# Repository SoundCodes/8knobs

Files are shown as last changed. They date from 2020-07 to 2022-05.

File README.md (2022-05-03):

# 8knobs
### Introducing 8knobs
IMAGE ALT TEXT (https://www.youtube.com/watch?v=3tVFqUqmMqI "8knobs")

###### // Synth // Midi controller // educational module 

8knobs is a portable synthesizer and  midi controller. Right out of the box  8knobs creates drones and atmospheres (ambient soundscapes). 8knobs encourages learning  synthesis, electronics, computer literacy and experimentation. Built on the popular Arduino platform it readily embodies the character of the user. It is an open source and hacker friendly instrument, ready to morph according to a wide range of use cases.

8knobs can be used as a MIDI controller through usb, as a plug-n-play device; this means no installations, no additional convertors, no headaches. The 8knobs DIY  kit consists of a PCB, an Arduino Atmega 32u4, header pins, potentiometers, all the necessary electronic components, mounting hardware, a laser cut wood veneer body and a case made of hand stitched jute with raw unbleached cotton. 

8knobs has 1 audio out, MIDI over USB or MIDI over 3.5mm to connect to other traditional synthesisers. It can be powered via USB, DC 9-12v wall adaptor or a 9v battery.

#### DIY 

###### // Electronics // Sound synthesis // Computer Coding

While building 8knobs you’ll learn everything from the basics like soldering to the fundamentals of sound synthesis, electronics and computer codes by understanding, engineering and experimenting with signal flow. Learn the art of signal flow by building your own custom synthesiser and controller for more experiments!

####Experience 

###### // Creative learning and new approaches

Getting familiar with signal flow unlocks a wide range of new opportunities to innovate and produce technical as well as creative applications in various media - both analog and digital.

Just like the flow of signals in the brain are interconnected and influence each other. For example, like neurons communicating information in both chemical and electrical forms, can result in infinite combinations of  thoughts, words, and actions, similarly, playing with signal flow in hardware (electronics), software (coding) and space (acoustics) can result in infinite creative expressions.  

The art of signal flow offers endless possibilities, and whether you take it up as a hobby or use it to pursue a life-changing innovation is for you to choose. Either way, it’s a great feeling to get your hands dirty in the energetic flow of signals and DIY culture!

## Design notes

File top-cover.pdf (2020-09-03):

## step 1:

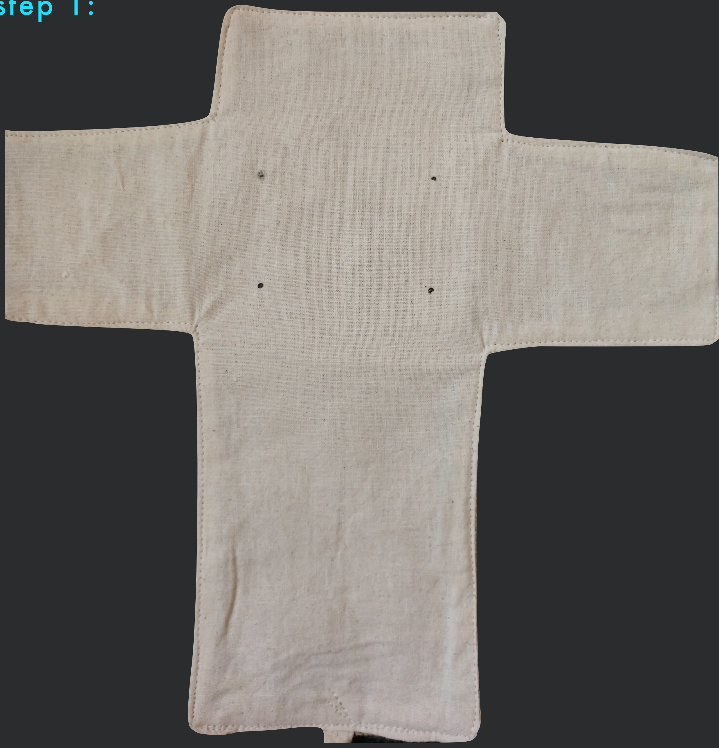
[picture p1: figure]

- Use the top cover to mark holes on the Jute cloth

## step 2:

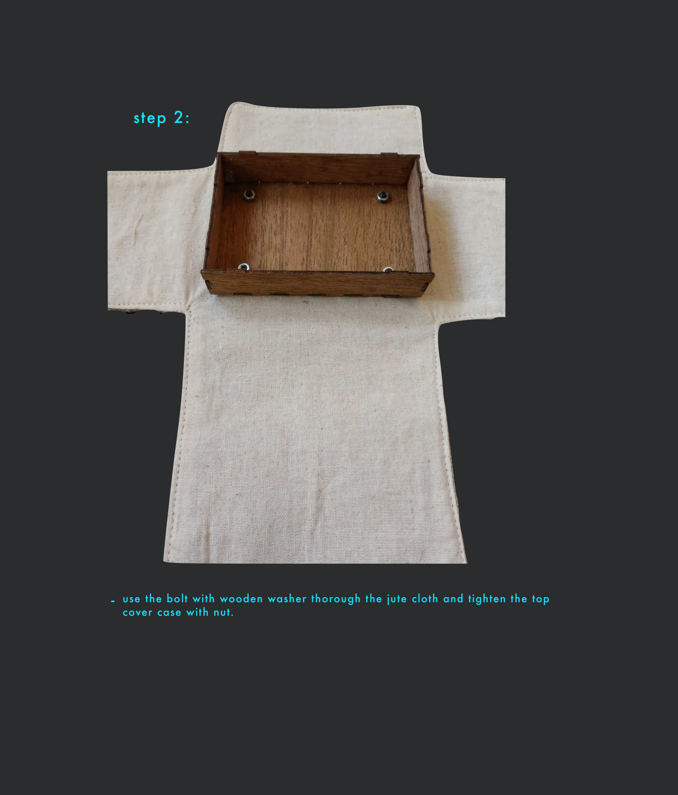
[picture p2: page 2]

- use the bolt with wooden washer thorough the jute cloth and tighten the top cover case with nut.

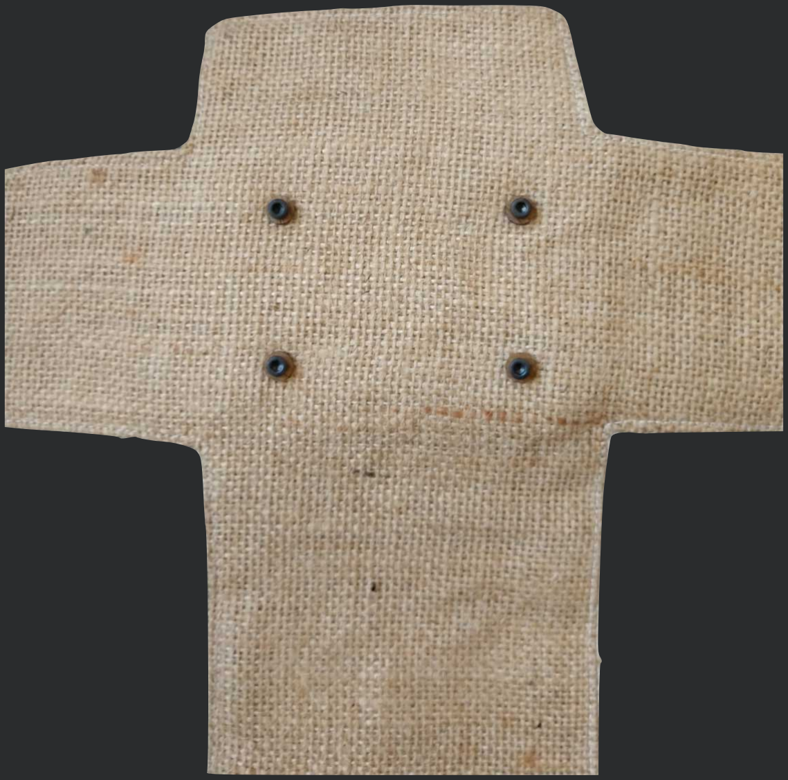
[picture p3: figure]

The Jute would look something like this after the process

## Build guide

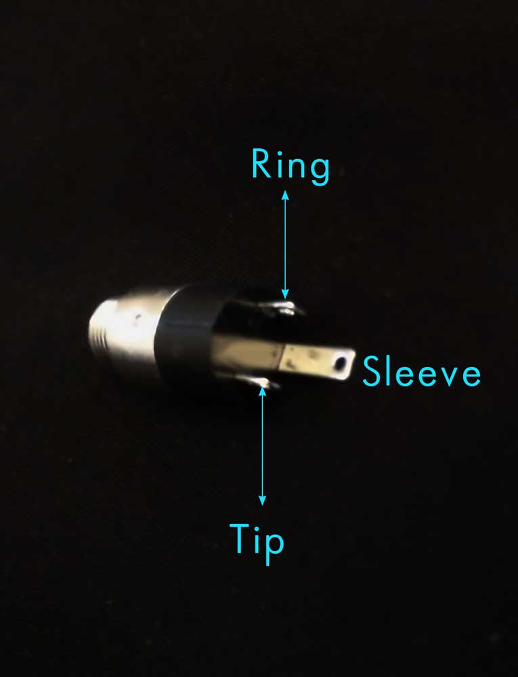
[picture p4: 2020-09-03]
DIY Instructions/3.5mm.jpg

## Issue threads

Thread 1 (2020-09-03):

Not clear how to solder jack for midi

60pfennig, 2020-09-03:
Hello :)
It is not clear for me which pin at the 3.5mm jack is for the tip and which is for the ring. Does it matter?
Greets Felix

SubstanceD, 2020-09-03:
Hey @60pfennig polarity of the 3.5mm stereo connector does matter.
On the back side of the connector it has tiny number printed. 1= tip, 2=ring
Also the below image may make it more clear.
https://github.com/SoundCodes/8knobs/blob/master/DIY%20Instructions/3.5mm.jpg

60pfennig, 2020-09-03:
Thanks for the clarification :)

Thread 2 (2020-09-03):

High Frequency Noise

60pfennig, 2020-09-03:
After soldering and assembling everything I tried 8knobs out. Everything works good but I get an very high pitched noise even if all oscillators are turned down. Is this because of the the arduino or did I made a mistake while soldering and there is flowing some current where it shouldnt flow?

SubstanceD, 2020-09-03:
Can be due to arduino or it can be one pot as well.. rapidly check which one is the culprit . This can be done by turning all pots down and rapidly turning one single pot to somewhere 30%-40% and bringing it back down to 0. Do this for all the pots.
If its on pot then its the soldering of the pot if not then its arduino. If its arduino then on the backside of the pcb you can solder an additional resistor anything between 10 to 100 ohm deadbug style.

If its pot then the easy fix is everytime do this action to the pot to cancel the Hi freq noise. ie bring it to some point like 30%-40% then rapidly bring it down.

60pfennig, 2020-09-03:
Ok, I cleaned all pcb because I thought maybe maybe the flux caused a current leak. Problem persists. I tried the knob thing. Every knob is modifying the volume of its osc. The hi freq still persists all the time on the same freq. On poti might be faulty, because even if I turn it completly down, the osc keeps playing on low rate.
To solver the hi freq problem I could try soldering an additional resistor. Where exactly should I solder it?

SubstanceD, 2020-09-03:
Ok..
R1 would be the place

60pfennig, 2020-09-03:
And I would take out the old one and replace it? If I solder it in parallel it would be useless I guess. I'm not that good in electronics, sorry! :)
Also I measured the pins I soldered with a multimeter and I was a little bit confused. All pins of the 6 pin connector seems to be connected and power is flowing between the pins. Did I somethin wrong or is it on purpose. I thought every knob is "sending" its resistance to the arduino via these pins. So I don't understand why these are connected.

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

SubstanceD, 2020-09-03:
True Parallel would do small change. If its precisely high frequency then it has to do with the register and capacitor relation?
Is it possible for you to know what is the high frequency ?
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
Is this it? 16k ?

60pfennig, 2020-09-11:
Hi, sorry for the delay. Yes my noise is also at 16kHz. This is what I get with every knob turned down..
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

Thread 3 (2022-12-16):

Unclear Build Instructions / BOM

Scablands, 2022-12-16:
I am working on building one of these units and am having trouble understanding the instructions.

The "What You Get" section of the instructions lists the following:
100k registor
270k registor
200uf capacitor

But in the actual steps of installing the components, the following are listed:
R2: 200k
R1: 270Ω
capacitor: 2.2uf

Why are all of these values different than the materials list? I have no idea which values are correct.

Could someone confirm which set of values for the components are the right ones? I also could not find the potentiometer values listed anywhere in the documentation, so if anyone has built one successfully, could you also let me know the values for those?

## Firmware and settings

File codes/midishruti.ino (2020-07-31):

/*
Midi CC output
currently set to control shurti synth
remove the 'map' if the output of the midi needs to be 0-127

*/

    
    #include "MIDIUSB.h"
  
              uint8_t old1Knob = 0;
              uint8_t new1Knob = 0;
          
              uint8_t old2Knob = 0;
              uint8_t new2Knob = 0;
          
              uint8_t old3Knob = 0;
              uint8_t new3Knob = 0;
          
              uint8_t old4Knob = 0;
              uint8_t new4Knob = 0;
          
              uint8_t old5Knob = 0;
              uint8_t new5Knob = 0;
          
              uint8_t old6Knob = 0;
              uint8_t new6Knob = 0;
          
              uint8_t old7Knob = 0;
              uint8_t new7Knob = 0;
          
              uint8_t old8Knob = 0;
              uint8_t new8Knob = 0;
  
    void setup()
    {}
    
    void loop()
    {
      // 1knob :  cut off  //  CC = 14    //  Range = 0 - 127
    
            uint16_t oneknob = analogRead(A0);
            uint8_t new1Knob = oneknob >> 3;
    
      if ( new1Knob != old1Knob )
      {
            midiEventPacket_t midiCc = { 0x0B, 0xB0, 14, new1Knob };
            MidiUSB.sendMIDI(midiCc);
            MidiUSB.flush();
            oneknob = new1Knob;
      }
    
      // 2knob :   res  //  CC = 15    // Range =  0 - 63
    
    
            uint16_t twoknob = analogRead(A1);
            uint8_t new2Knob = twoknob >> 3;
    
      if ( new2Knob != old2Knob )
      {
            midiEventPacket_t midiCc = { 0x0B, 0xB0, 15, new2Knob / 2 };
            MidiUSB.sendMIDI(midiCc);
            MidiUSB.flush();
            twoknob = new2Knob;
      }
    
      //  3knob :   osc 1 shape  // CC = 20     // Range = 0 - 34
    
            uint16_t threeknob = analogRead(A2);
            uint8_t new3Knob = threeknob >> 3;
          //new3Knob = map(new3Knob, 0, 127, 0, 127);
    
      if ( new3Knob != old3Knob )
      {
            midiEventPacket_t midiCc = { 0x0B, 0xB0, 20, new3Knob };
            MidiUSB.sendMIDI(midiCc);
            MidiUSB.flush();
            threeknob = new3Knob;
      }
    
    
      // 4knob :   osc1 pwm     // CC =  21     // Range 0 - 127
    
            uint16_t fourknob = analogRead(A3);
            uint8_t new4Knob = fourknob >> 3;
      
      if ( new4Knob != old4Knob )
      {
            midiEventPacket_t midiCc = { 0x0B, 0xB0, 21, new4Knob };
            MidiUSB.sendMIDI(midiCc);
            MidiUSB.flush();
            fourknob = new4Knob;
      }
    
    
      //   5knob :   lfo 1 rate  // CC = 113    // Range = 0 - 143
    
    
            uint16_t fiveknob = analogRead(A4);
            uint8_t new5Knob = fiveknob >> 3;
          
    
      if ( new5Knob != old5Knob )
      {
            midiEventPacket_t midiCc = { 0x0B, 0xB0, 113, new5Knob };
            MidiUSB.sendMIDI(midiCc);
            MidiUSB.flush();
            fiveknob = new5Knob;
      }
    
    
      //   6knob :   osc2  // CC =  24     //  Range 0 - 34
    
    
            uint16_t sixknob = analogRead(A5);
            uint8_t new6Knob = sixknob >> 3;
          //new6Knob = map(new6Knob, 0, 127, 0, 34);
    
      if ( new6Knob != old6Knob )
      {
            midiEventPacket_t midiCc = { 0x0B, 0xB0, 24, new6Knob };
            MidiUSB.sendMIDI(midiCc);
            MidiUSB.flush();
            sixknob = new6Knob;
      }
    
    
      //   7knob :   osc2 para   // CC =  25     // Range = 0 - 127
    
    
            uint16_t sevenknob = analogRead(A6);
            uint8_t new7Knob = sevenknob >> 3;
    
      if ( new7Knob != old7Knob )
      {
            midiEventPacket_t midiCc = { 0x0B, 0xB0, 25, new7Knob };
            MidiUSB.sendMIDI(midiCc);
            MidiUSB.flush();
            sevenknob = new7Knob;
      }
    
    
      //   8knob :   env 1 R   CC = 107    //  Range = 0 - 127
    
    
            uint16_t eightknob = analogRead(A7);
            uint8_t new8Knob = eightknob >> 3;
    
      if ( new8Knob != old8Knob )
      {
            midiEventPacket_t midiCc = { 0x0B, 0xB0, 107, new8Knob };
            MidiUSB.sendMIDI(midiCc);
            MidiUSB.flush();
            eightknob = new8Knob;
      }
    
    }

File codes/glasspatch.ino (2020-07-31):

/*  
  8 control rate oscillators are used to set the volume of 8 audio oscillators.
  ran readings from a feedback are used to set the notes
  being played, and Feedback readings from a Feedback dependent resistor are
  mapped to the pulse rates of the volume control oscillators.
  
  Build from the code of
  Tim Barrass 2013, CC by-nc-sa.
*/
#include <MozziGuts.h>
#include <Oscil.h>
#include <tables/cos8192_int8.h>
#include <mozzi_midi.h>

#define CONTROL_RATE 256

#define knob1 A0
#define knob2 A1
#define knob3 A2
#define knob4 A3
#define knob5 A4
#define knob6 A5
#define knob7 A6
#define knob8 A7
#define THRESHOLD 5

// harmonics
Oscil<COS8192_NUM_CELLS, AUDIO_RATE> aCos1(COS8192_DATA);
Oscil<COS8192_NUM_CELLS, AUDIO_RATE> aCos2(COS8192_DATA);
Oscil<COS8192_NUM_CELLS, AUDIO_RATE> aCos3(COS8192_DATA);
Oscil<COS8192_NUM_CELLS, AUDIO_RATE> aCos4(COS8192_DATA);
Oscil<COS8192_NUM_CELLS, AUDIO_RATE> aCos5(COS8192_DATA);
Oscil<COS8192_NUM_CELLS, AUDIO_RATE> aCos6(COS8192_DATA);
Oscil<COS8192_NUM_CELLS, AUDIO_RATE> aCos7(COS8192_DATA);
Oscil<COS8192_NUM_CELLS, AUDIO_RATE> aCos0(COS8192_DATA);

// volume controls
Oscil<COS8192_NUM_CELLS, CONTROL_RATE> kVol1(COS8192_DATA);
Oscil<COS8192_NUM_CELLS, CONTROL_RATE> kVol2(COS8192_DATA);
Oscil<COS8192_NUM_CELLS, CONTROL_RATE> kVol3(COS8192_DATA);
Oscil<COS8192_NUM_CELLS, CONTROL_RATE> kVol4(COS8192_DATA);
Oscil<COS8192_NUM_CELLS, CONTROL_RATE> kVol5(COS8192_DATA);
Oscil<COS8192_NUM_CELLS, CONTROL_RATE> kVol6(COS8192_DATA);
Oscil<COS8192_NUM_CELLS, CONTROL_RATE> kVol7(COS8192_DATA);
Oscil<COS8192_NUM_CELLS, CONTROL_RATE> kVol0(COS8192_DATA);

// audio volumes updated each control interrupt and reused in audio till next control
char v1,v2,v3,v4,v5,v6,v7,v0;

// notes to play depending on whether ran reading increases or decreases
float upnotes[knob3] = {
  //59, 60, 62, 65, 67, 71, 72
  mtof(59.f),mtof(60.f),mtof(62.f),mtof(65.f),mtof(67.f),mtof(71.f), mtof(72.f)};
//72, 71, 69, 67, 69, 65, 64, 61,  67, 65, 64, 62, 64, 59,60
float downnotes[knob3] = {
  mtof(72.f),mtof(71.f),mtof(69.f),mtof(67.f),mtof(69.f),mtof(65.f),mtof(64.f),mtof(61.f),mtof(67.f),mtof(65.f),mtof(64.f),mtof(62.f),mtof(64.f),mtof(59.f),mtof(60.f)};
  

void setup(){
  startMozzi(CONTROL_RATE);
}


// returns freq
int ranToFreq(char oscil_num, int ran){
  static int previous_ran;
  int freq;
  if (ran>previous_ran){
    freq = upnotes[oscil_num];
  } else {
     freq = downnotes[oscil_num];
  }
  previous_ran = ran;
  return freq;
}


void updateControl(){
  static float previous_pulse_freq;
    
  // read analog inputs
  int ran = mozziAnalogRead(knob1); // not calibrated to degrees!
  int Feedback = mozziAnalogRead(knob2);

  // map Feedback reading to volume pulse frequency
  float pulse_freq = (float)Feedback/256;
  previous_pulse_freq = (1023-mozziAnalogRead(knob3))/256;

  v0 = kVol0.next();
  v1 = kVol1.next();
  v2 = kVol2.next();
  v3 = kVol3.next();
  v4 = kVol4.next();
  v5 = kVol5.next();
  v6 = kVol6.next();
  v7 = kVol7.next();
  
  // set one note oscillator frequency each time (if it's volume is close to 0)
  static char whoseTurn;
  switch(whoseTurn){  
  case 0:
    kVol0.setFreq((1023-mozziAnalogRead(knob4))/256);
    if(abs(v0)<THRESHOLD) aCos0.setFreq(ranToFreq(0,ran));
    break;

  case 1:
    kVol1.setFreq((1023-mozziAnalogRead(knob5))/256);
    if(abs(v1)<THRESHOLD) aCos1.setFreq(ranToFreq(1,ran));
    break;

  case 2:
    kVol2.setFreq((1023-mozziAnalogRead(knob6))/256);
    if(abs(v2)<THRESHOLD) aCos2.setFreq(ranToFreq(2,ran));
    break;

  case 3:
    kVol3.setFreq((1023-mozziAnalogRead(knob7))/256);
    if(abs(v3)<THRESHOLD) aCos3.setFreq(ranToFreq(3,ran));
    break;

  case 4:
    kVol4.setFreq((1023-mozziAnalogRead(knob7))/256);
    if(abs(v4)<THRESHOLD) aCos4.setFreq(ranToFreq(4,ran));
    break;

  case 5:
    kVol5.setFreq((1023-mozziAnalogRead(knob8))/256);
    if(abs(v5)<THRESHOLD) aCos5.setFreq(ranToFreq(5,ran));
    break;
//
  case 6:
    kVol6.setFreq((1023-mozziAnalogRead(knob1))/256);
    if(abs(v6)<THRESHOLD) aCos6.setFreq(ranToFreq(6,ran));
    break;

  case 7:
    kVol7.setFreq((1023-mozziAnalogRead(knob2))/256);
    if(abs(v7)<THRESHOLD) aCos7.setFreq(ranToFreq(7,ran));
    break;

  }

  if(++whoseTurn>=knob3) whoseTurn = 0;
}



int updateAudio(){
  long asig = (long)
    aCos0.next()*v0 +
      aCos1.next()*v1 +
      aCos2.next()*v2 +
      aCos3.next()*v3 +
      aCos4.next()*v4 +
      aCos5.next()*v5 +
      aCos6.next()*v6 +
      aCos7.next()*v7;
  asig >>= 9; // shift back to audio output range
  return (int) asig;
}



void loop(){
  audioHook();
}
